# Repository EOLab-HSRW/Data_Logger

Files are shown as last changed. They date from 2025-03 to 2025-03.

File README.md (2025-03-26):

# Data Logger

## Description

This project simplifies data logging to external storage (SD card / EEPROM).

## Content

- [Hardware](#hardware)
- [Documentation](#documentation)
- [Data Types](#data-types)
- [EEPROM Data Storage Simulation](#eeprom-data-storage-simulation)
- [Data Storage Management](#data-storage-management)
- [Power Consumption Simulation](#power-consumption-simulation)
- [Power Consumption Simulation with Liquid Level Sensor](#power-consumption-simulation-with-liquid-level-sensor)
- [Modification: Addition of Liquid Sensor](#modified-data-logger--addition-of-the-liquid-level-sensor)

## Hardware

### RawWireless WisBlock

| Component  | Price (€) | Description |
|---|---|---|
| RAK11200 | 13.16 | ESP32-based module with WiFi & BLE |
| RAK11310 | 17.01 | Raspberry Pi-based module with LoRa transceiver |
| RAK19002 | 06.65 | Power slot module (Li-Ion, USB-C, Solar) |
| RAK15000 | 15.96 | EEPROM module |
| RAK15002 | 04.90 | SD card module |
| RAK12002 | 09.50 | RTC Module |
| RAK19011 | 20.90 | Development Board |
| RAK19012 | 06.90 | Development Board |
| RAK5802 | 07.97 | Interface |
| RAK1906 | 20.21 | Environmental sensor module |
| RS485 | 06.00 | Liquid level sensor + connector |
| **Total**  | **129.16** | |

## Documentation

For datasheets, quick guides, and detailed descriptions, visit:  
[docs.RawWireless.com](https://docs.RawWireless.com)

## Software

- **IDE:** Arduino IDE  
- **Project files:** Included in the project folder  

## Data Types

### 1. Timestamp  
### 2. Environmental Sensor:
   - Temperature
   - Pressure
   - Humidity
   - Gas
### 3. Liquid Level Sensor:
   - Liquid Level
   - Water Pressure

## EEPROM Data Storage Simulation

### Properties

- **Endurance:** 1 million write cycles
- **Size:** 2Mb (2,097,152 bits), organized as 262,144 words (8-bit format)
- **Power:** Standby current ~3 µA  
- **Write Mode:** 256-byte page writes (reduces wear)
- **Voltage:** 3.3V (can be controlled via the core)

### Restrictions

- **Capacity:** 2MB
- **Estimated endurance:** 2-3 months

### Storage Calculation

#### Option 1 (Without Optimization)

- 1 × 32-bit Unix timestamp
- 1 × 32-bit temperature
- 1 × 32-bit pressure
- 1 × 32-bit humidity
- 1 × 32-bit gas level
- 1 × 32-bit liquid level / water pressure
- 1 × 32-bit voltage level  
**Total:** 224 bits  

**Iterations:**  
`(2^20 * 2) / 224 = 9,362`

#### Option 2 (Optimized Storage)

- 1 × 32-bit Unix timestamp
- 1 × 16-bit temperature (-40°C to 85°C)
- 1 × 32-bit pressure
- 1 × 16-bit humidity (0% to 100%)
- 1 × 32-bit gas level
- 1 × 32-bit liquid level / water pressure (0 mm to 5000 mm)
- 1 × 16-bit voltage level (0V to 24V)  
**Total:** 144 bits  

**Iterations:**  
`(2^20 * 2) / 144 = 14,564`

**Difference:** +5,201 iterations with optimization.

### EEPROM RAK15000

- **Size:** 2Mb (2 × 2^20 = 2,097,152 bits)  
- **Storage:** Linear, sequential  
- **Address range:** 262,144 addresses (1 byte per address)

### EEPROM RAK11200 (Internal)

- **Size:** 64Kb (524,288 bits)  
- **Storage:** Linear, sequential  
- **Address range:** 16-bit (0x0000 to 0xFFFF)  
- **Note:** May contain pre-configured LoRaWAN data.

## **Metadata and Storage Layout**

EEPROM data storage is structured to ensure efficient tracking and retrieval. 
The first **8 bytes (64 bits)** are reserved for metadata:

1. **Write Counter** (20-bit) → Tracks total write cycles  
2. **Storage Position Counter** (18-bit) → Tracks the next writable address
3. **Empty Bits** (26 Bits) -> For Future Usage

**Total Metadata Size:** 64 bits

- **Write Counter:** 20 bits (supports up to 1,000,000 cycles = `0xF4240`)  
- **Storage Position Counter:** 18 bits (supports up to 262,144 addresses)  
- **Total Reserved Space:** 8 bytes

## EEPROM Data Reader / Decoder

### **Reading Process**
EEPROM contains two main sections:  
1. **Metadata:** First **8 bytes** (Indexes 0-7) store counters and tracking information.  
2. **Sensor Data Blocks:** Data is stored in **sets of 32 bytes**, following a specific sequence:
   - Temperature  
   - Pressure  
   - Humidity  
   - Gas resistance  
   - RTC timestamp

## Data Erasure Before Switching Context/Sensors

### Steps to Erase Data:

1. **Collected Data Backup:** Before erasing, ensure any necessary data is backed up.
2. **Overwrite:** With standart Value of 0x00.
3. **Metadata Reset:** is done automatically by step 2 (Overwrite).
4. **Metadata Configuration:** Setting the Address Counter to Byte 8 (0-7 Metadata).
5. **Date and Time Configuration:** Setting the Date and Time of the RTC. 

## Power Consumption Simulation

### Normal Mode

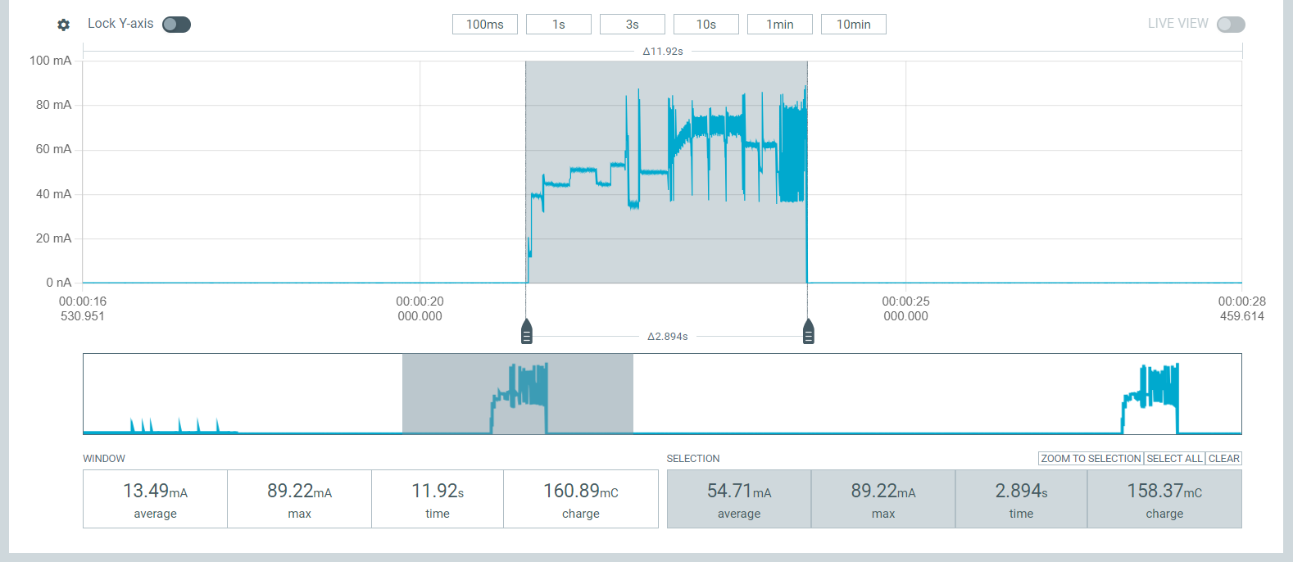
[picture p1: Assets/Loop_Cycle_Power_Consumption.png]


**Results:**

Average power consumption during deep sleep was 54.71 mA over a duration of 2.894 seconds. The battery life calculation considered the following parameters:

- Code execution duration: 3.9 seconds
- Sleep time: 1200 seconds
- Consumption during code execution: 55.03 mA
- Consumption in sleep mode: 54.71 mA
- Battery capacity: 2500 mAh with 20% discharge safety margin.

### DeepSleep Mode

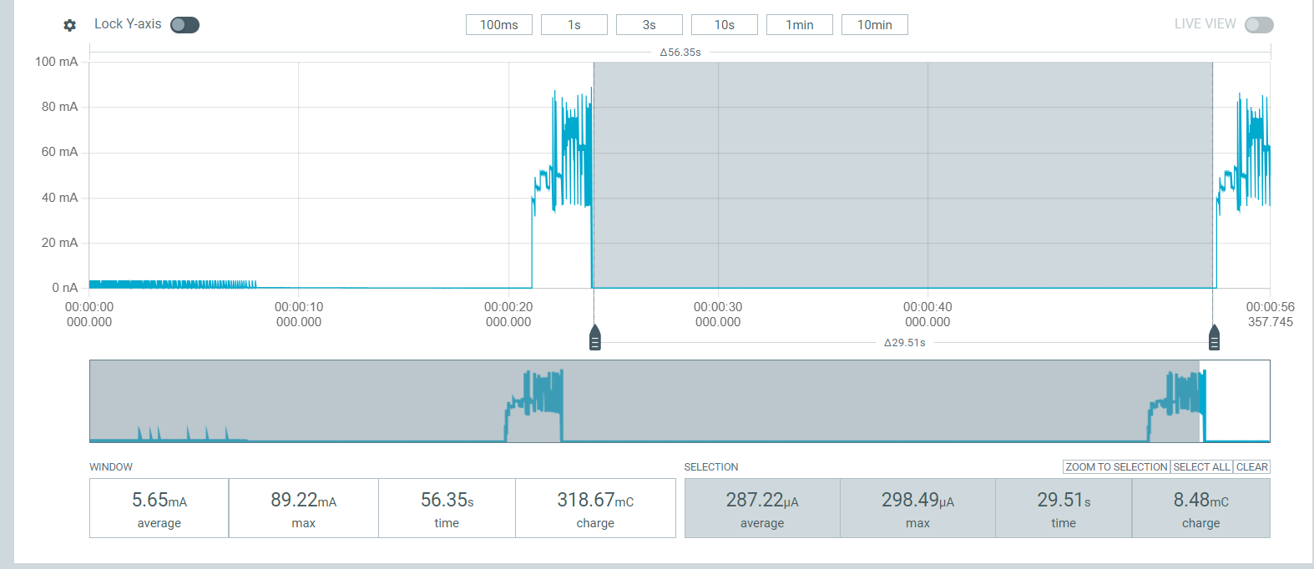
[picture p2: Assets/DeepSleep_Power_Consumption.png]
DeepSleep Mode Test Results


**Results:**

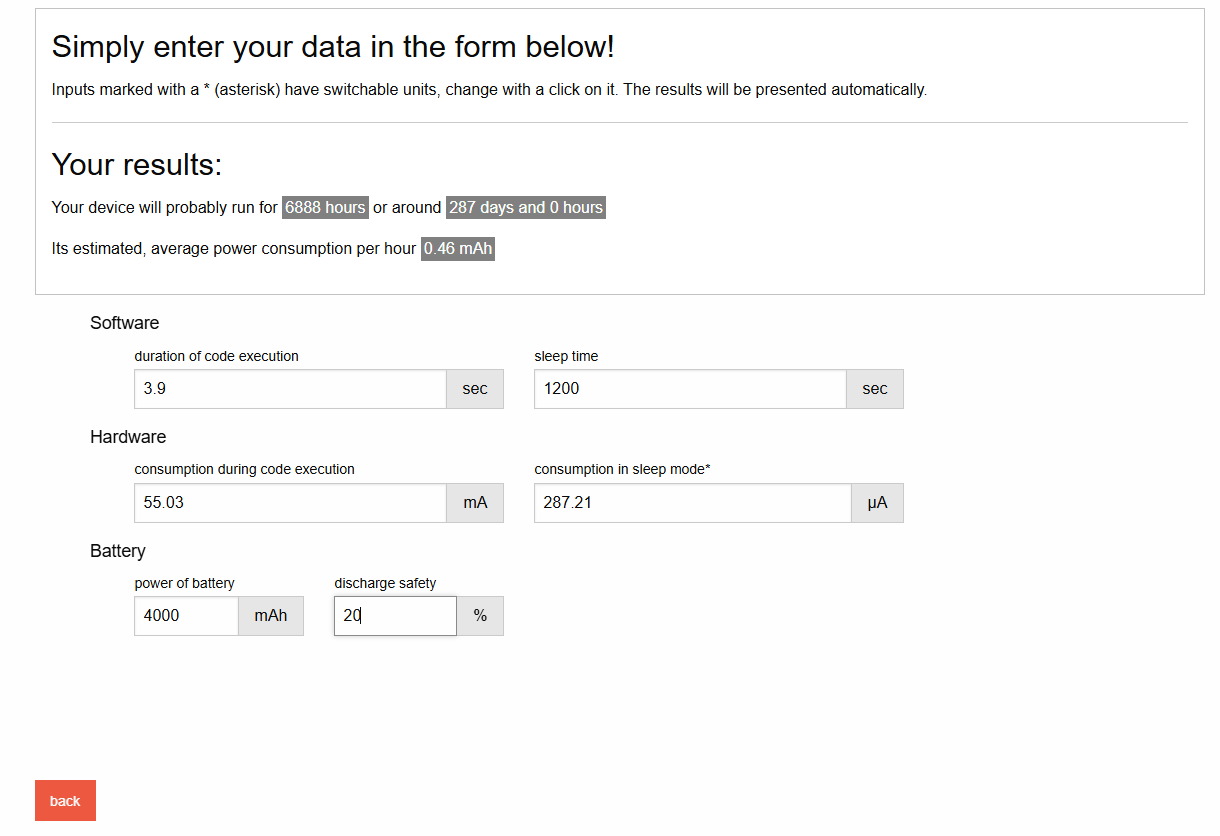
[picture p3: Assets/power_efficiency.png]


Average power consumption during deep sleep was 287.22 µA over a duration of 29.51 seconds. The battery life calculation considered the following parameters:

- Code execution duration: 3.9 seconds
- Sleep time: 1200 seconds
- Consumption during code execution: 55.03 mA
- Consumption in deep sleep mode: 287.21 µA
- Battery capacity: 2500 mAh with 20% discharge safety margin.

Estimated battery life: approximately 4305 hours, equivalent to around 179 days and 9 hours. Estimated average power consumption per hour: 0.46 mAh.

## Power Consumption Simulation with Liquid Level Sensor

### Normal Mode

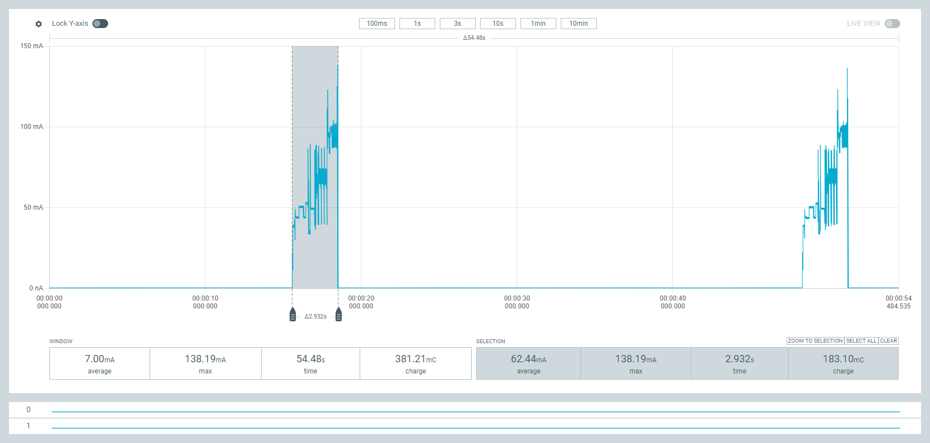
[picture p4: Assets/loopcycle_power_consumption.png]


**Results:**

Average power consumption during deep sleep was 62.44 mA over a duration of 2.932 seconds. The battery life calculation considered the following parameters:

- Code execution duration: 2.932 seconds
- Sleep time: 1200 seconds
- Consumption during code execution: 62.44 mA
- Consumption in sleep mode: 311.72 mA
- Battery capacity: 4000 mAh with 20% discharge safety margin.

### DeepSleep Mode

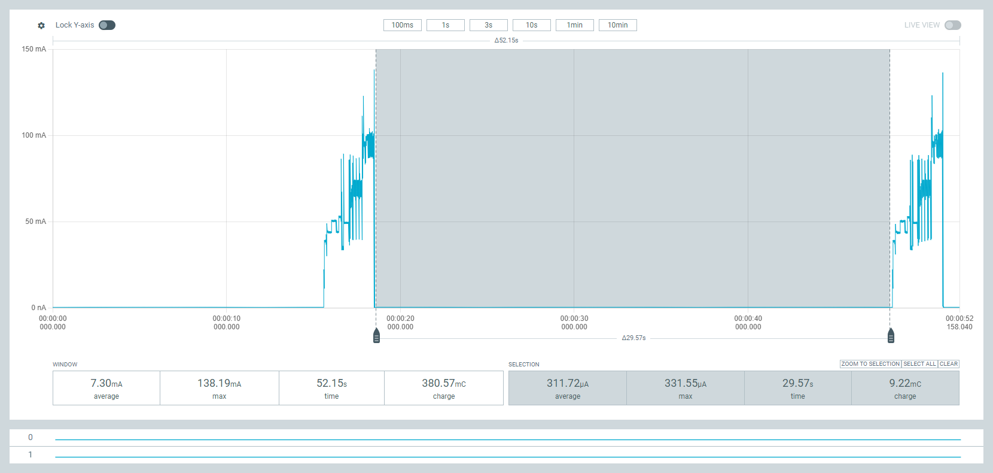
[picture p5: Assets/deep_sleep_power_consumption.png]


**Results:**

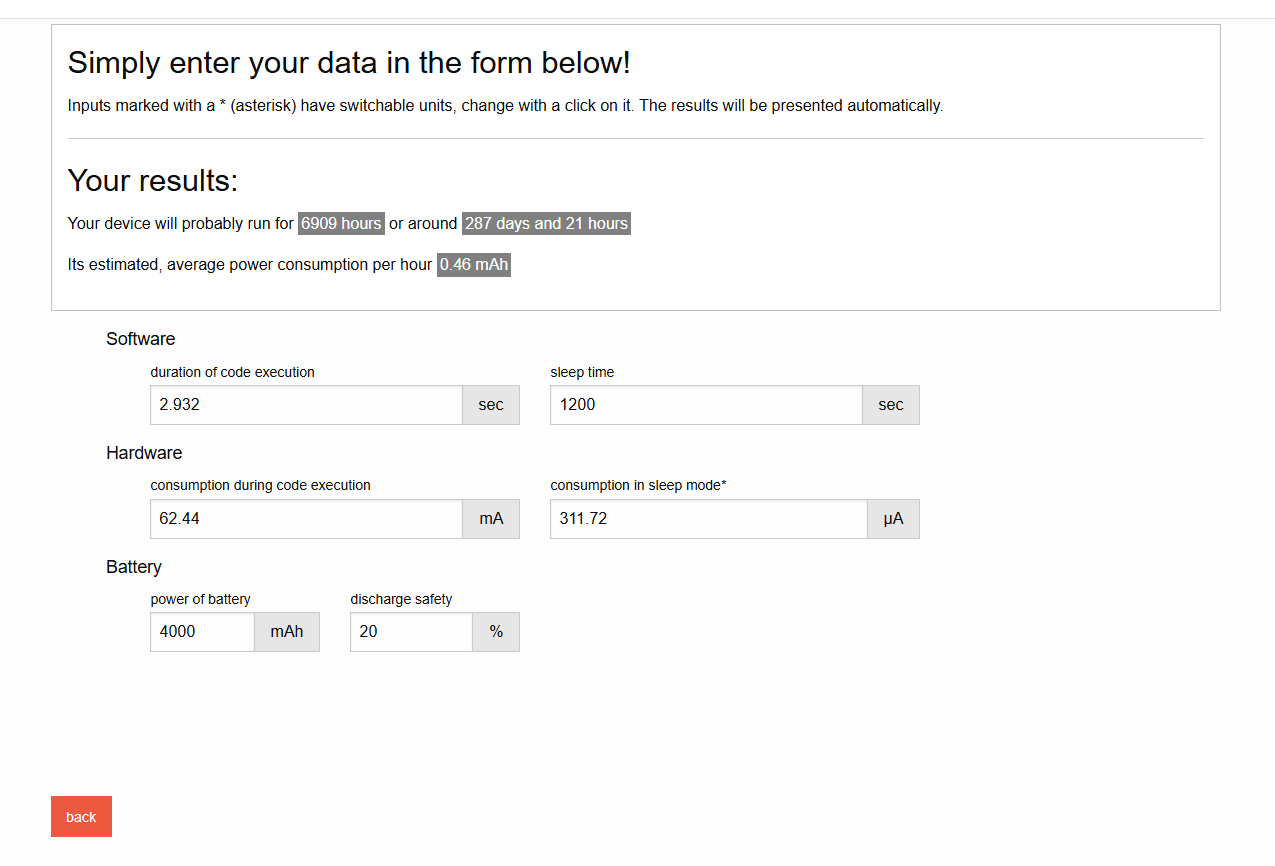
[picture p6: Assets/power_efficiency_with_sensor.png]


Average power consumption during deep sleep was 311.72 µA over a duration of 29.57 seconds. The battery life calculation considered the following parameters:

- Code execution duration: 2.932 seconds
- Sleep time: 1200 seconds
- Consumption during code execution: 62.44 mA
- Consumption in sleep mode: 311.72 mA
- Battery capacity: 4000 mAh with 20% discharge safety margin.

Estimated battery life: approximately 6909 hours, equivalent to around 287 days and 21 hours. Estimated average power consumption per hour: 0.46 mAh.

## Modified Data Logger / Addition of the Liquid Level Sensor

### RS485 Liquid Level Sensor

#### Overview
The **RS485 Liquid Level Sensor** is a high-precision sensor designed for measuring liquid levels. 

#### Features
**Anti-corrosion material** – Durable and resistant  
**Modbus-RTU communication** – Compatible with PLCs, displays, and data loggers  
**High-precision sensor** – ±0.25% accuracy  
**Wide operating voltage** – 11–30V DC  
**Fast response time** – ≤ 5 ms  

### Technical Specifications

| Parameter | Value |
|---|---|
| **Measurement Range** | 0 ~ 5 meters |
| **Output** | RS485 (Modbus-RTU) |
| **Accuracy** | ±0.25% F.S. |
| **Temperature Range** | -40°C to +85°C |
| **Material** | 304/316L Stainless Steel |
| **Power Supply** | 11–30V DC |
| **Weight** | 670 g |

#### Wiring
The sensor is connected via an **Aviation Connector** interface. The pin configuration is:

| Pin | Description |
|-----|---|
| 12V (RAK5801) | 12V Power Supply (VCC Sensor)  |
| A1  (RAK5801) | GND (GND Sensor) |

#### Modbus-RTU Communication
#### Default Communication Settings:
- **Baud Rate**: 9600 bps (supports 1200–115200 bps)
  **Note:** Changes to baud rate and slave address take effect immediately. If not, restart the sensor.

### RAK5801 Sensor Module

#### Overview
The **RAK5801** is a high-performance sensor module designed for industrial and environmental monitoring applications. 
Part of the WisBlock ecosystem, it offers robust data acquisition and is engineered for reliable performance even in harsh conditions.

#### Features
- **High-Precision Measurement** – accurate data collection.
- **Rugged Design** –  reliably in industrial environments.
- **Seamless Integration** – Easily integrates.
- **Versatile Interfaces** – Supports standard communication protocols.

### RAK19002 Sensor Module

#### Overview
The **RAK19002** is a sensor module developed for versatile IoT applications within the WisBlock ecosystem.
It is designed to provide reliable, accurate measurements for various environmental and application-specific parameters.

#### Features
- **Compact & Low Power** – Optimized for energy-efficiency.
- **High Accuracy** – Ensures precise measurement data.
- **Plug-and-Play Integration** – interfaces with WisBlock.
- **Robust Performance** – Suitable for operating conditions.

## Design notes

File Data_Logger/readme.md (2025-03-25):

# **Software Documentation: Arduino Data Logger**

## Content

- [Overview](#1-overview)
- [File Structure](#2-file-structure)
- [System Workflow](#3-system-workflow)
- [Function Summary](#4-functions-summary)
- [Data Isolation / Storage](#5-isolation-of-counter-and-storage-data)
- [Future Enhancements](#6-future-enhancements)

## **1. Overview**
This project implements a data logging system using an Arduino-compatible microcontroller. The system reads environmental sensor data, stores it in EEPROM, and writes it to an SD card. Additionally, it integrates a Real-Time Clock (RTC) for timestamping logged values.

## **2. File Structure**
The project consists of several modules:

### **2.1 datalogger.ino**
- **Purpose:** Main entry point of the application.
- **Functionality:**
  - Initializes required components (SD card, EEPROM, BME680 sensor, and RTC).
  - Collects environmental sensor data.
  - Manages data storage in EEPROM and SD card.
  - Ensures proper communication and handling of time-sensitive operations.

### **2.2 bme680_sensor.h / bme680_sensor.cpp**
- **Purpose:** Interface for the BME680 environmental sensor.
- **Functionality:**
  - Initializes the BME680 sensor and configures its settings.
  - Reads temperature, pressure, humidity, and gas resistance values.
  - Ensures data consistency by converting floating values to integers (x100 scaling).
  - Provides both static and dynamic memory allocation options for sensor data retrieval.

### **2.3 eeprom.h / eeprom.cpp**
- **Purpose:** EEPROM memory management.
- **Functionality:**
  - Initializes EEPROM communication over I2C.
  - Provides functions for reading and writing data to EEPROM.
  - Implements memory addressing logic to ensure sequential data storage.
  - Includes power control for EEPROM.

### **2.4 sdcard.h / sdcard.cpp**
- **Purpose:** SD card file management.
- **Functionality:**
  - Provides functions to read, write, and delete files on an SD card.
  - Uses SPI communication for SD card access.
  - Supports CSV-style data logging with automatic separation.
  - Implements error handling for file operations.
### **2.5 rtc.h / rtc.cpp**
- **Purpose:** Real-Time Clock (RTC) management.
- **Functionality:**
  - Provides functions to retrieve the current time in a specified format.
  - Uses I2C communication for interaction with the RTC module.
  - Supports setting and updating the date and time.
  - Includes functions for reading from and writing to the internal EEPROM.
  - Implements error handling for RTC operations.

## **3. System Workflow**
1. **Initialization:**
   - The system starts by initializing serial communication, EEPROM, SD card, RTC, and the BME680 sensor.
   - It checks the presence and accessibility of each module.

2. **Data Collection:**
   - The main loop collects sensor readings every 5 minutes using `get_Environment()`.
   - The retrieved data is formatted and prepared for storage.

3. **Data Storage:**
   - Data is split into 8-bit chunks and stored in EEPROM sequentially.
   - The same data is written to the SD card for long-term storage.

4. **Error Handling:**
   - The system checks for sensor availability and EEPROM communication before reading or writing data.
   - Serial messages indicate any failures, such as missing EEPROM or SD card issues.

## **4. Functions Summary**
| Function Name | File | Description |
|---|---|---|
| `void get_Values()` | datalogger.ino | Retrieves sensor data and prints it via serial. |
| `bool bme680_init()` | bme680_sensor.cpp | Initializes the BME680 sensor. |
| `void get_Environment(long values[])` | bme680_sensor.cpp | Reads sensor values and converts them to integers. |
| `bool eeprom_init()` | eeprom.cpp | Initializes and verifies EEPROM availability. |
| `void readData(long address)` | eeprom.cpp | Reads data from EEPROM. |
| `void writeData(long* data, size_t size)` | eeprom.cpp | Writes data to EEPROM and increments the address counter. |
| `long getCounter()` | eeprom.cpp | Returns the extracted Total Counter. |
| `void setCounter(long counter)` | eeprom.cpp | Sets the Total Counter. |
| `void getAddress()` | eeprom.cpp | Returns the extracted Address Counter. |
| `void setAddress(long address)` | eeprom.cpp | Sets the Address Counter. |
| `void readFile(const char *path)` | sdcard.cpp | Reads a file from the SD card and prints its content. |
| `void writeFile(const char *path, const char *message)` | sdcard.cpp | Appends data to an SD card file with CSV formatting. |
| `void deleteFile(const char *path)` | sdcard.cpp | Deletes a specified file from the SD card. |
| `String combineToString(long *data, size_t size)` | sdcard.cpp | Combines the collected data into one String. |
| `void rtc_init()` | rtc.cpp | Initializes and verifies RTC availability. |
| `unsigned long rtcGetTimeLong()` | rtc.cpp |  Returns the current time. |

## **5. Isolation of Counter and Storage Data**

### **64 Bit Meta Data**

```
0000 0000 0000 0000 0000 0000 0000 0000 0000 0000 0000 0000  0000 0000 0000 0000
------------------------                                                         Total (20)
                         ----------------------                                  Address (18)
                                               --------------------------------- Free (26)
```

---

### **Total Counter Isolation**
| Step | Description |
|---|---|
| **1** | Read **Byte 1-3** (Indexes 0-2) |
| **2** | Perform a Bit Shift by 4 to the right on the third byte |
| **3** | Perform a Bit Shift by 4 to the left to restore the original value |
| **4** | Convert to `long` to obtain the exact value from the bytes |
| **5** | Shift the first byte 16 bits to the left |
| **6** | Shift the second byte 8 bits to the left |
| **7** | Sum all values to get the final total |

### **Total Counter Reset**
| Step | Description |
|---|---|
| **1** | Generate 3 masks to extract the 20 bits from the long parameter |
| **2** | Masks: `0xff0000`, `0x00ff00`, and `0x0000ff` |
| **3** | Set byte 1 and byte 2 with the extracted values |
| **4** | Read byte 3 again, perform a bit shift by 4 to the left and right to align with subsequent metadata |
| **5** | Perform an OR operation with the adjusted `val3` and set the third byte |

---

### **Address Counter Isolation**
| Step | Description |
|---|---|
| **1** | Read **Byte 3-5** (Indexes 2-4) |
| **2** | Perform a Bit Shift by 4 to the right on the second byte |
| **3** | Perform a Bit Shift by 4 to the left to restore the original value |
| **4** | Convert to `long` to obtain the exact value from the bytes |
| **5** | Shift the first byte 16 bits to the left |
| **6** | Shift the third byte 8 bits to the left |
| **7** | Sum all values to get the final address |

### **Address Counter Reset**
| Step | Description |
|---|---|
| **1** | Generate 3 masks to extract the 20 bits from the long parameter |
| **2** | Masks: `0xff0000`, `0x00ff00`, and `0x0000ff` |
| **3** | Set byte 2 with the extracted value |
| **4** | Read byte 1 and byte 3 again, perform a bit shift by 6 to the left and right for byte 3, and by 4 to the left and right for byte 1 to align with subsequent metadata |
| **5** | Perform an OR operation with `val1` and `val3` from behind and set the first and third bytes |

---

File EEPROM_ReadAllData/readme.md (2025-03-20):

# EEPROM Reader

This project demonstrates how to read data from an I2C EEPROM and write it to an SD card. The system is built with an ESP32, EEPROM module, and an SD card module. It features initialization functions for the EEPROM and SD card, as well as data retrieval functions to read from the EEPROM and write the data to a file on the SD card.

## Features

### `sdcard_init()`
Initializes the SD card module and checks for a successful connection. This function ensures that the SD card is properly mounted and ready for writing.

### `writeFile(path, message)`
Writes a message to a file on the SD card. If the file doesn't exist, it is created. This function is used to store the data read from the EEPROM to the SD card.

### `eeprom_init()`
Initializes the EEPROM module and verifies the connection over I2C. It ensures that the EEPROM is properly connected to the ESP32 and ready for data reading.

### `readData(address, buffer, size)`
Reads data from the EEPROM at a specified address and stores it in the provided buffer. This function is used to retrieve both metadata and sensor data from the EEPROM.

### `getMetaData()`
This function reads the first 8 bytes of the EEPROM (the metadata) and processes the information. It calculates the total counter, address, and available free space based on the EEPROM contents.

### `getSensorData(counterAddress, i)`
This function reads sensor data from the EEPROM at a specific address and converts the data into a float value. The values are divided by 100 to convert them into a human-readable format (unless the value represents a timestamp). This function is used to process sensor readings for logging.

## Hardware Requirements

- ESP32 RAK11200
- EEPROM RAK15000
- SD-Module RAK15002

## Used Libraries

- [Adafruit EEPROM I2C](https://github.com/adafruit/Adafruit_EEPROM_I2C)
- [SD](https://www.arduino.cc/en/Reference/SD)

## Code Walkthrough

### Setup Process

1. **Serial Initialization:**
   The code starts by initializing the Serial communication at a baud rate of 115200. This allows you to monitor the progress of the program in the Serial Monitor.

2. **Initializing EEPROM and SD Card:**
   The functions `eeprom_init()` and `sdcard_init()` are called to initialize both the EEPROM and the SD card. These functions ensure that both components are correctly connected and operational.

3. **Reading Meta Data:**
   The `getMetaData()` function is called to read the first 8 bytes of data from the EEPROM. This metadata provides useful information about the EEPROM's state, such as the total counter, address, and available space. This data is then written to a file on the SD card as `Eeprom.csv`.

4. **Reading Sensor Data:**
   The program then reads sensor data from the EEPROM. A loop is used to read the data in chunks (50 sensor readings in this example). It reads 4 bytes at a time (each value is 4 bytes), and the data is processed by the `getSensorData()` function, which converts the raw bytes into float values. These values are then written to the SD card.

5. **Writing to SD Card:**
   The `writeFile()` function is used to write the meta data and sensor data to the SD card. The sensor data is written in CSV format, where each sensor reading is followed by a comma, and new lines are added after every 8 sensor readings.

### Main Functions

#### `getMetaData()`
The `getMetaData()` function reads 8 bytes from the EEPROM (the metadata section). It extracts and calculates important values such as:

- **Total Counter:** The total number of data points in the EEPROM.
- **Address:** The starting address for the sensor data.
- **Free Space:** The available space left in the EEPROM.

This metadata is formatted into a CSV string and returned.

#### `getSensorData(counterAddress, i)`
This function reads sensor data from the EEPROM at the specified address. It extracts 4 bytes of data and combines them into a single long value. This value is then divided by 100 to convert it into a floating-point value (except for timestamps, which are left as raw values). The processed data is returned as a string, and if it is the last value in a set, a newline character is added.

### Code Structure

The code is organized into different files:

- **`calculator.h`**: Contains declarations for the `getMetaData()` and `getSensorData()` functions.
- **`eeprom.h`**: Contains the functions related to reading data from the EEPROM.
- **`sdcard.h`**: Contains the functions related to initializing and writing data to the SD card.

Each of these files is included in the main Arduino file for initialization and processing of data.

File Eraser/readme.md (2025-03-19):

# Eraser

This project provides a simple library for working with I2C EEPROMs using Arduino. 
The library includes functions to initialize the EEPROM, reset data, and configure the address.

## Features

### `eeprom_init()`
Initializes the EEPROM connection via I2C and checks if the EEPROM is present.

### `readData(address, buffer, size)`
Reads data from the EEPROM at a specified address and stores it in the provided buffer.

### `reset(size)`
Overwrites the first `size` bytes of the EEPROM with the value `0xFF`.

### `configAddress()`
Sets the default value for the EEPROM address counter to manage the memory correctly.

## Hardware Requirements

- ESP32  RAK11200
- EEPROM RAK15000

## Used Libraries

- [Adafruit EEPROM I2C](https://github.com/adafruit/Adafruit_EEPROM_I2C)

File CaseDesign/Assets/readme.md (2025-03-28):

# Case Design and Model

## Box4u Case Details

### Base

The base of the case has the following specifications:
- Rounded corners (R6)
- Outer dimensions approximately 122/121.3 mm (width) and 120/119.3 mm (height)
- Main rectangle dimensions: width 116/115.3 mm (with a tolerance of +/- 0.35 mm), height 114/113.3 mm
- Inner dimensions (main section): width 97.2/96.5 mm, height 77.2/76.5 mm, depth 4/6.5 mm
- Cutouts: ø3 mm and ø8.5 mm

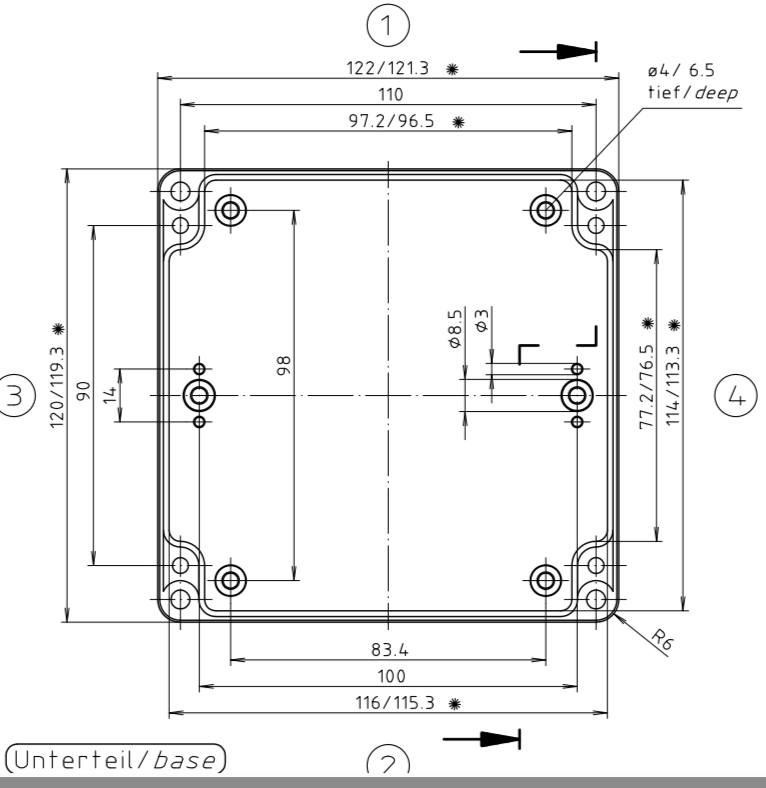
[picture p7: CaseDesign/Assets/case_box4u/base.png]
Base Sketch


### Lid

The lid of the case has the following specifications:
- Rounded corners (R6)
- Outer dimensions 122/121.5 mm (width) and 120/119.5 mm (height)
- Main rectangle dimensions: width 113/112.6 mm (with a tolerance of +/- 0.35 mm), height 111/110.6 mm
- Inner dimensions (main section): width 94.2/93.8 mm, height 74.2/73.8 mm

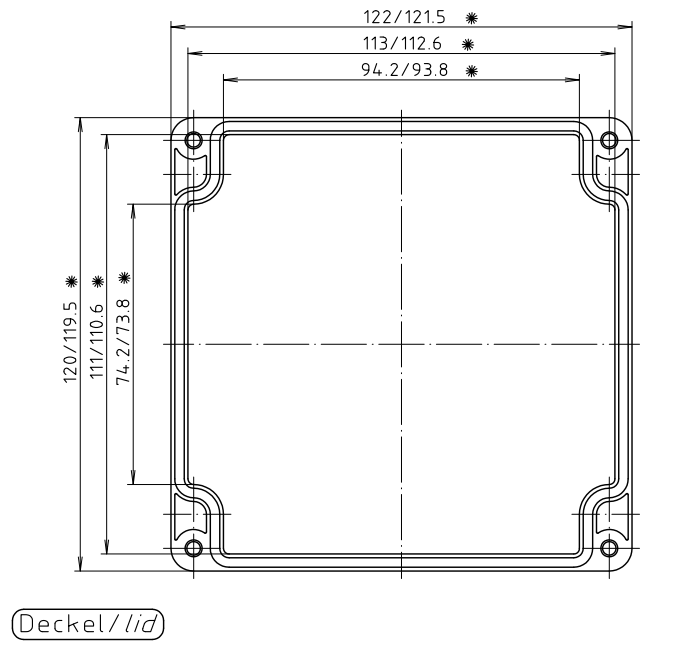
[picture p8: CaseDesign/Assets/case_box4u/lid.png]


### Depth

The side view reveals the following specifications:

Lid:
- 15 mm depth including 3 mm thickness on top of the lid
- Total height of 55 mm
- Height without bottom and top plate thickness: 48 mm
- 40 mm including 4 mm bottom plate for the base case

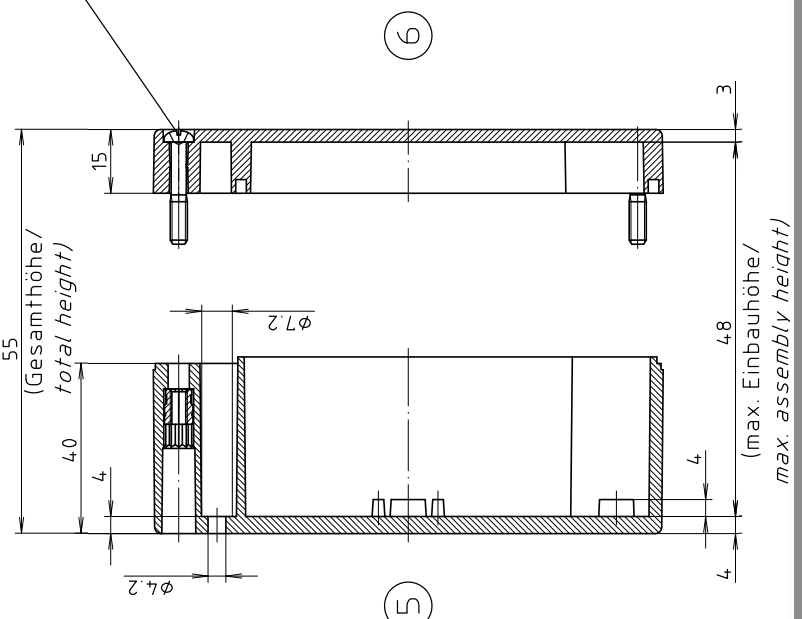
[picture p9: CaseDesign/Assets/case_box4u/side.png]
Side View


### Screw Detail

Cylinder Screws (M4 x 24 / 10 (DIN EN ISO 7045/))

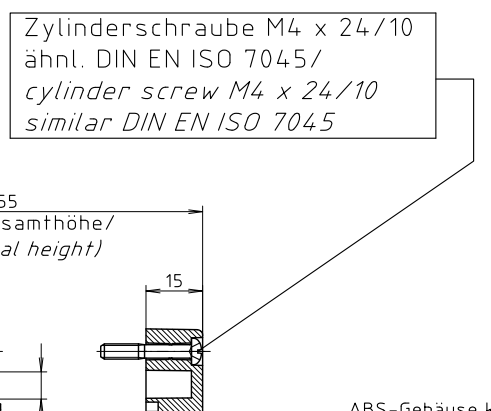
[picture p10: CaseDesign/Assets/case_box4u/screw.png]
Detail of Screw


## RAK Base Board Details

The board has the following specifications:
- a main rectangle of 69 (width) to 67 (height)
- 3 rectangular cutouts with 2x of 8mm * 14.50 and 1x 13 mm * 8mm
- 4x screw holes (inner radius of ø2.5 mm) / (outer radius ø5 mm)

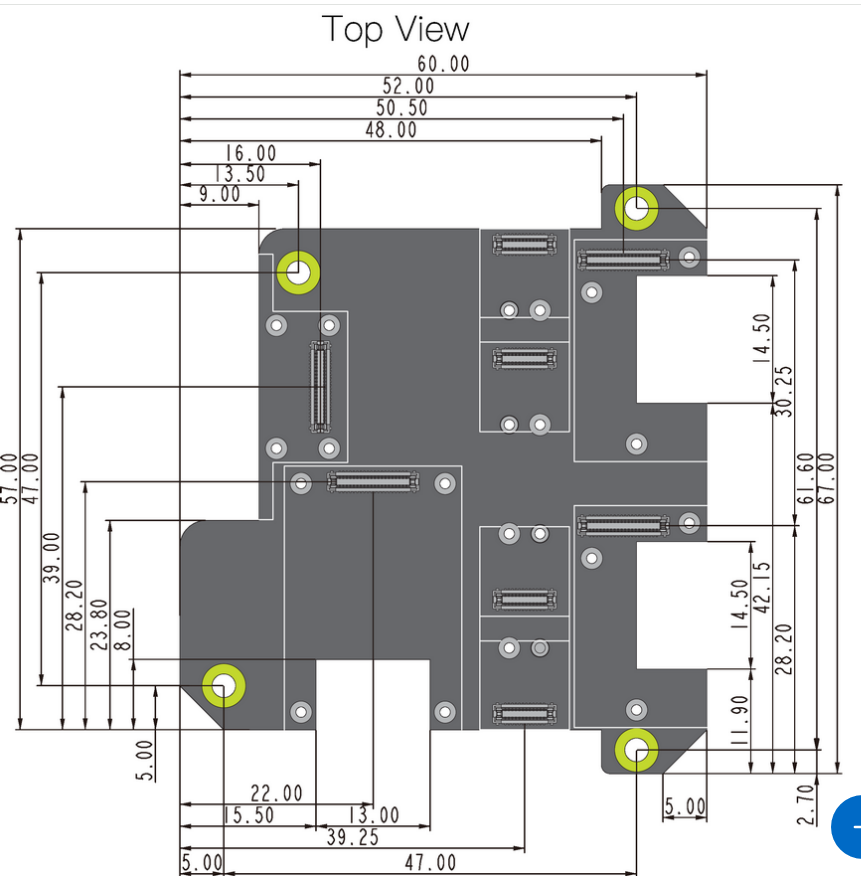
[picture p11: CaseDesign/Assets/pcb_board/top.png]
Board Sketch Top

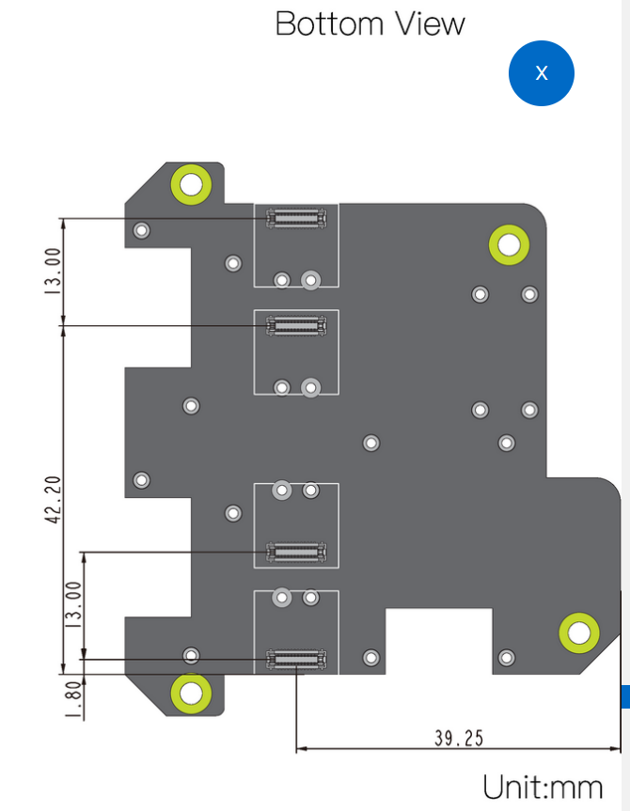
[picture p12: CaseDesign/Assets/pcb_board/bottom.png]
Board Sketch Bottom


## 3D Modelling in Auto Fusion 360

### Step 1: Basement

We start with the sketch of the basement.
Configure the sizes as mentioned earlier above.
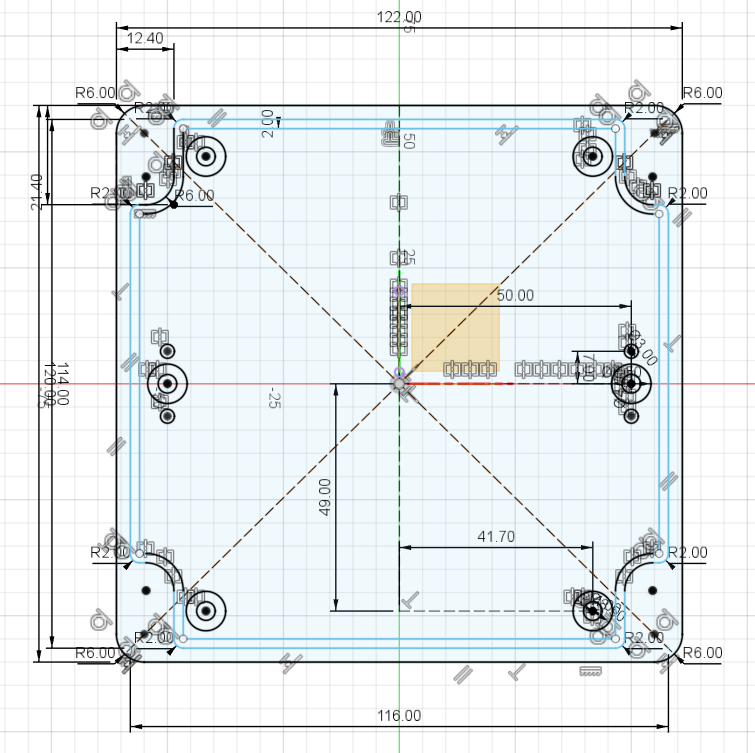
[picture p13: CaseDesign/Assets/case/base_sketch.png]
Base Sketch

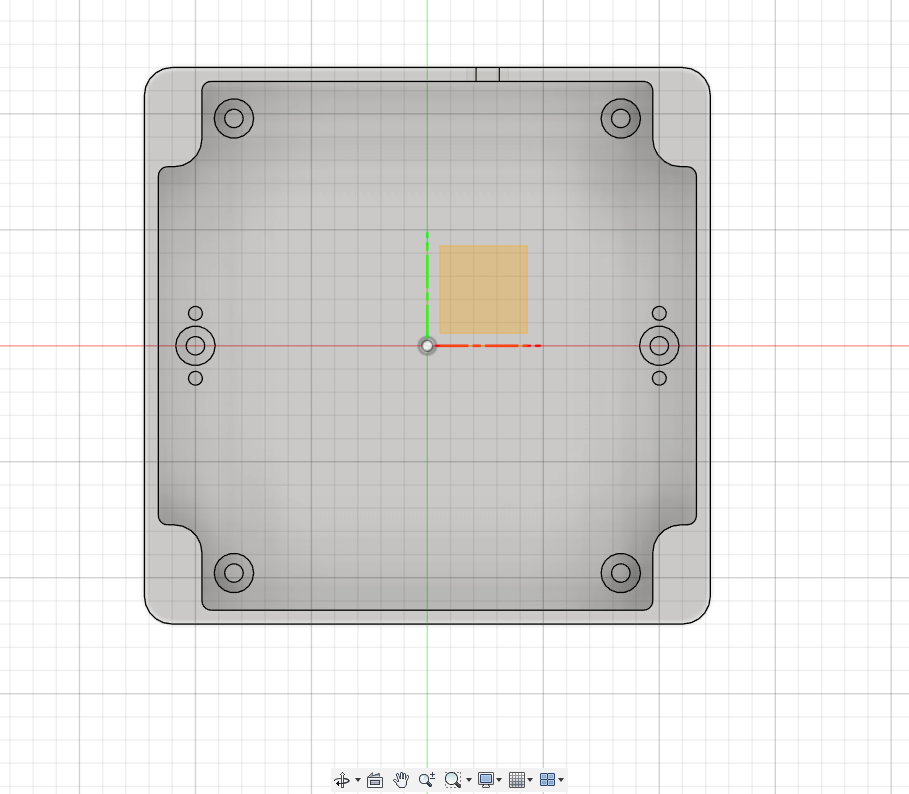
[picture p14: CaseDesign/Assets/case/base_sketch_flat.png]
Base Sketch Flat


Then we extrude the needed areas for the sides and also the outer circles for the screws.
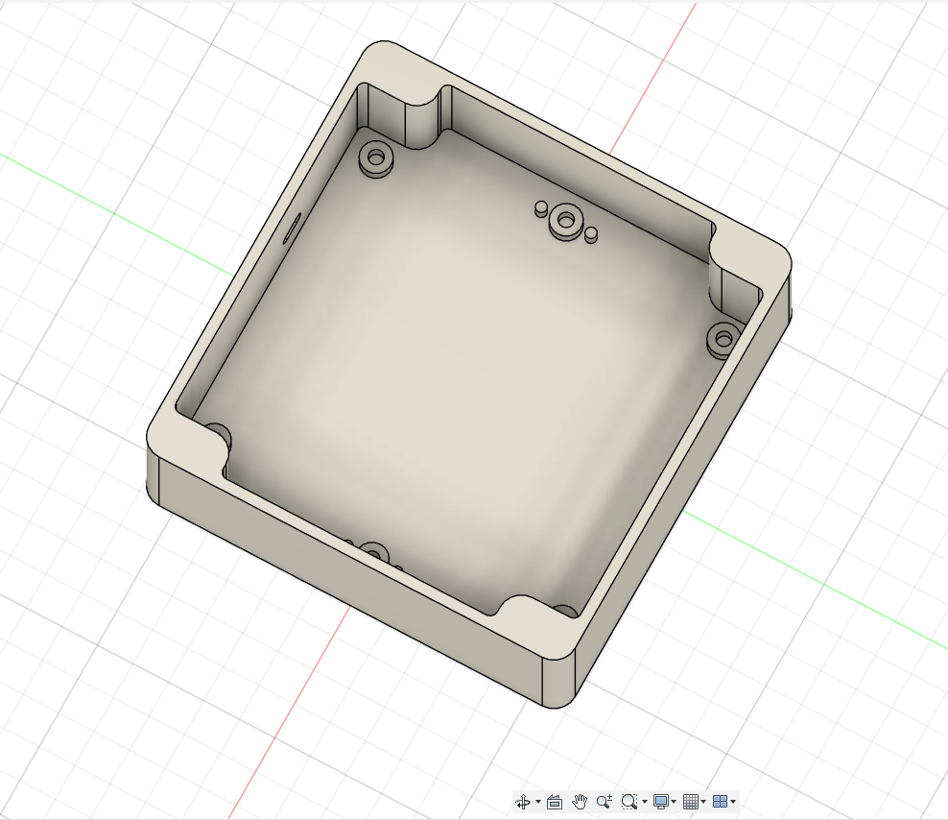
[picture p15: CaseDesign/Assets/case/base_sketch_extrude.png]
Base Sketch Extrude


### Step 2: Lid

Next, configure the sizes for the lid as in step 1.

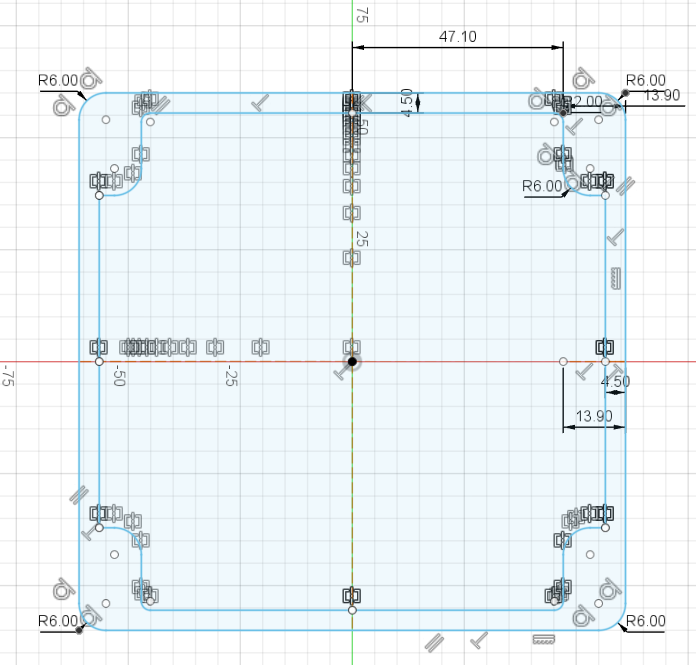
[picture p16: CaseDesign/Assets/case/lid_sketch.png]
Lid Sketch

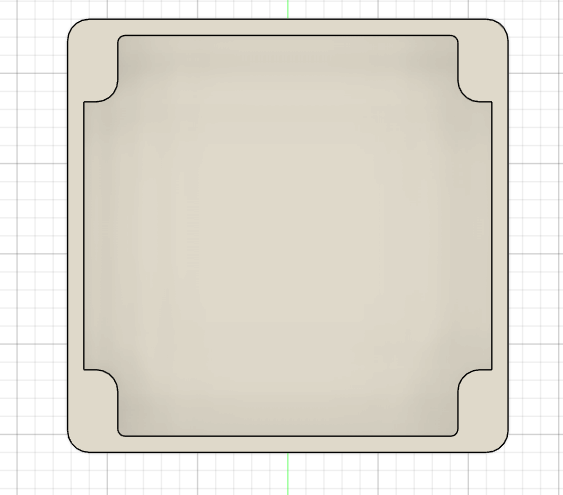
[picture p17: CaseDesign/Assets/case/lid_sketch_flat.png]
Lid Sketch Flat


Extrude the specified areas.

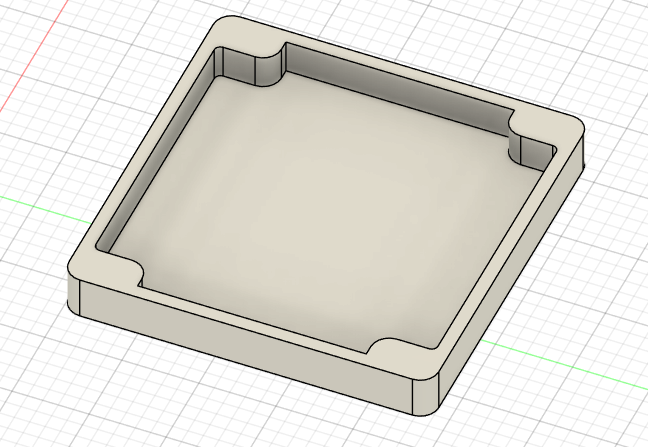
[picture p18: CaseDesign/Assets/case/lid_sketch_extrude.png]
Lid Sketch Extrude


### Step 3: Board

Continue with the RAK board sketch and set the sizes as shown.
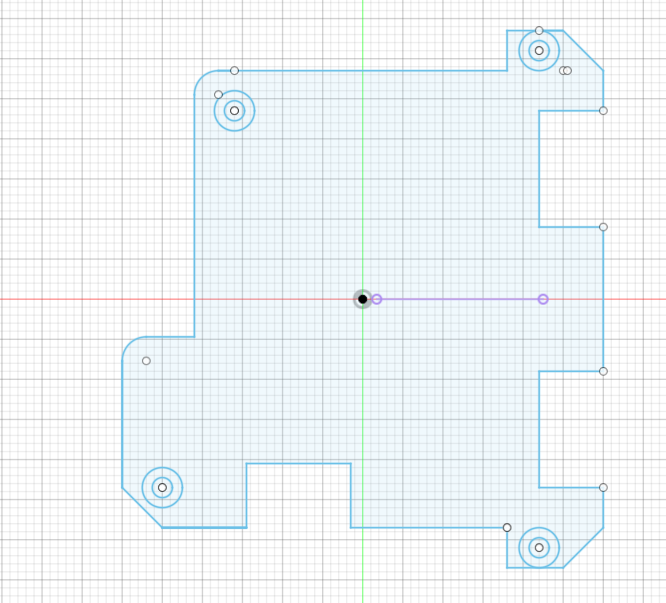
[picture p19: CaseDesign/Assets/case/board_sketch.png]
Board Sketch

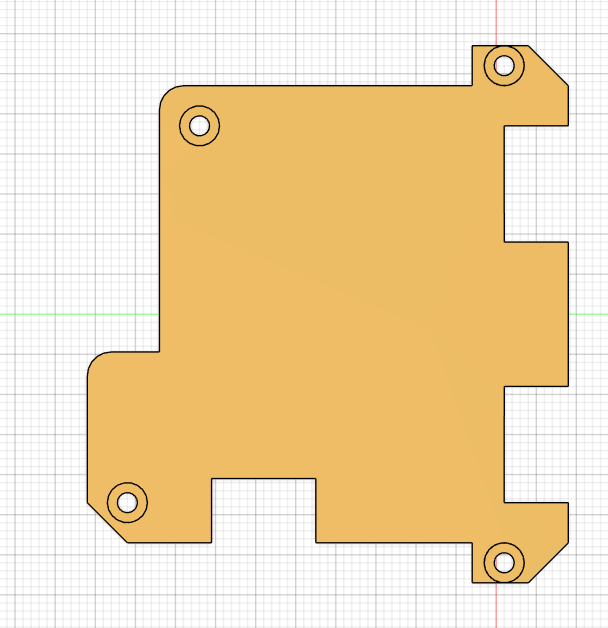
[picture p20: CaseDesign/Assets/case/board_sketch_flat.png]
Board Sketch Flat


Extrude the needed areas.
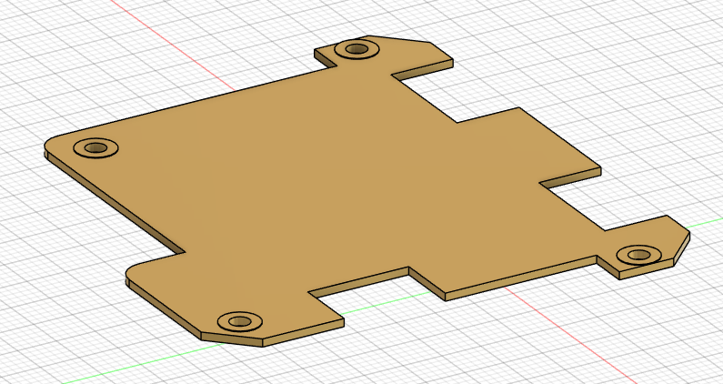
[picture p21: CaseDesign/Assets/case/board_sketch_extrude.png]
Board Sketch Extrude


### Step 4: Outline Basement

Set the sizes for the basement outline to fasten the board on the case.
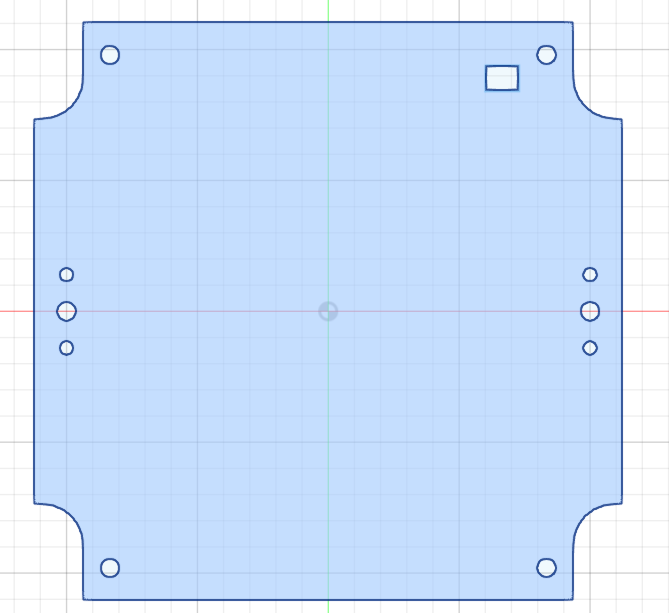
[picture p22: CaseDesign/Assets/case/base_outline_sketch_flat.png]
Base Outline Sketch Flat


Finish with an extrude of the needed areas.
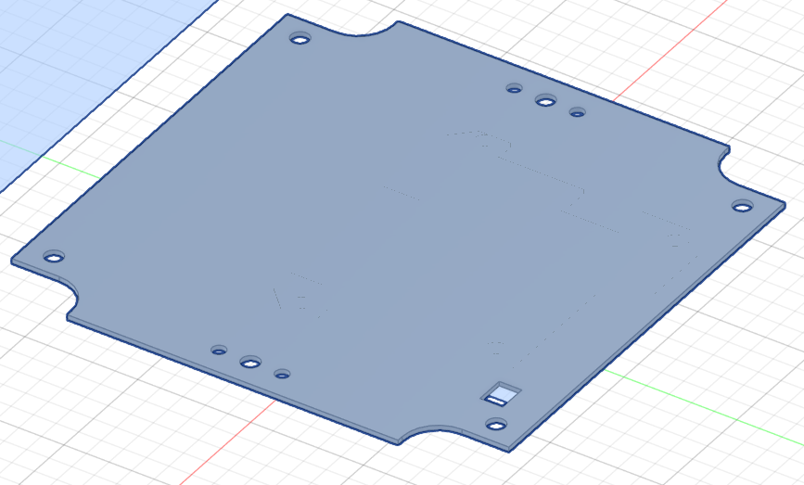
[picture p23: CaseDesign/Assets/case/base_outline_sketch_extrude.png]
Base Outline Sketch Extrude


### Step 5: Results

The results should be as follows:
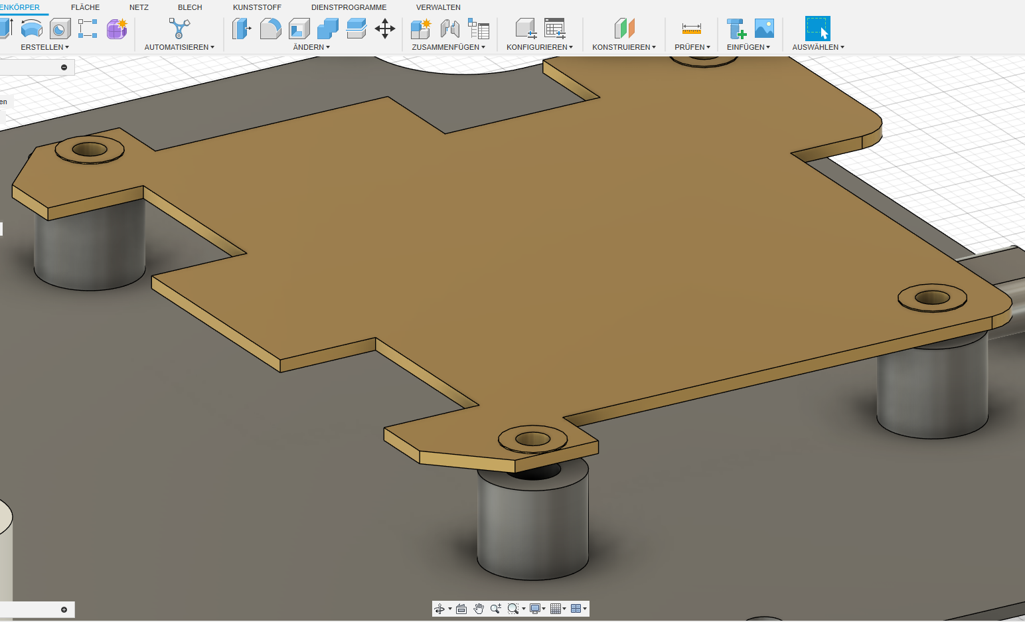
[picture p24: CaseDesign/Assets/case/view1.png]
View

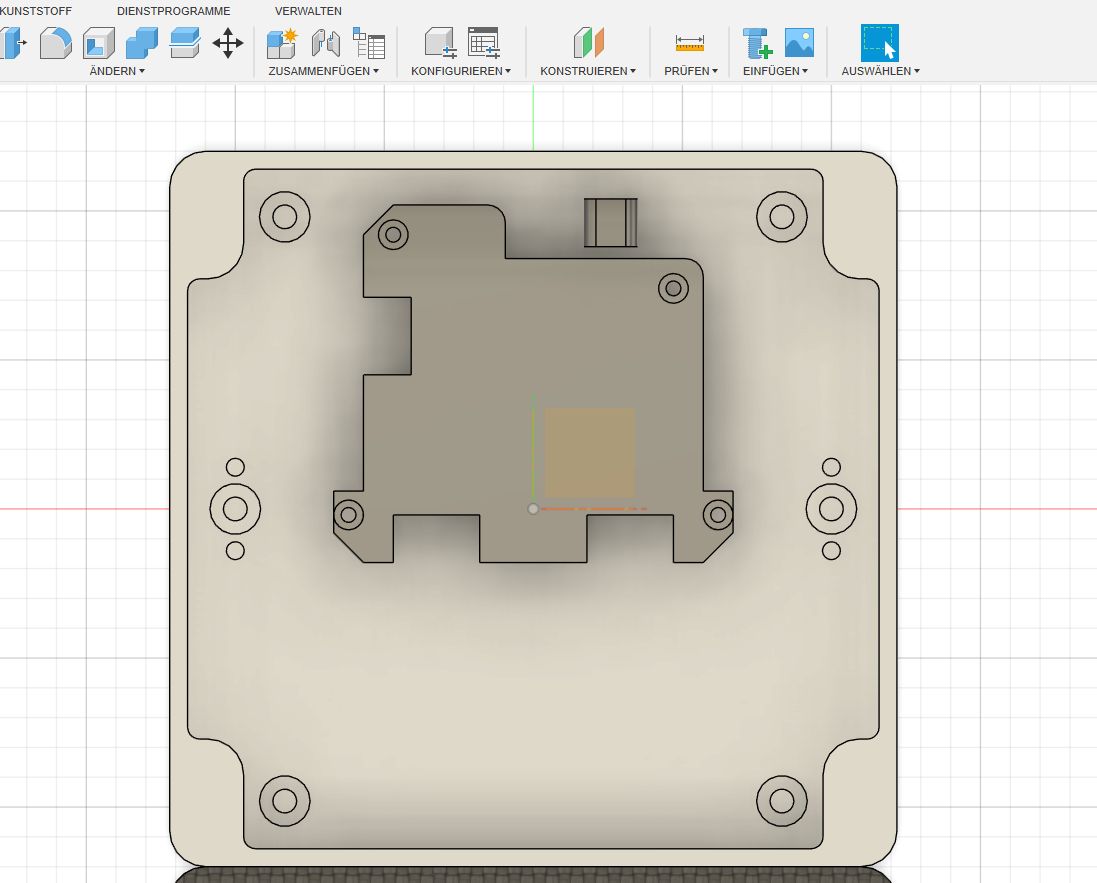
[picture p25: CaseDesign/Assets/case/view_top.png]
Top View

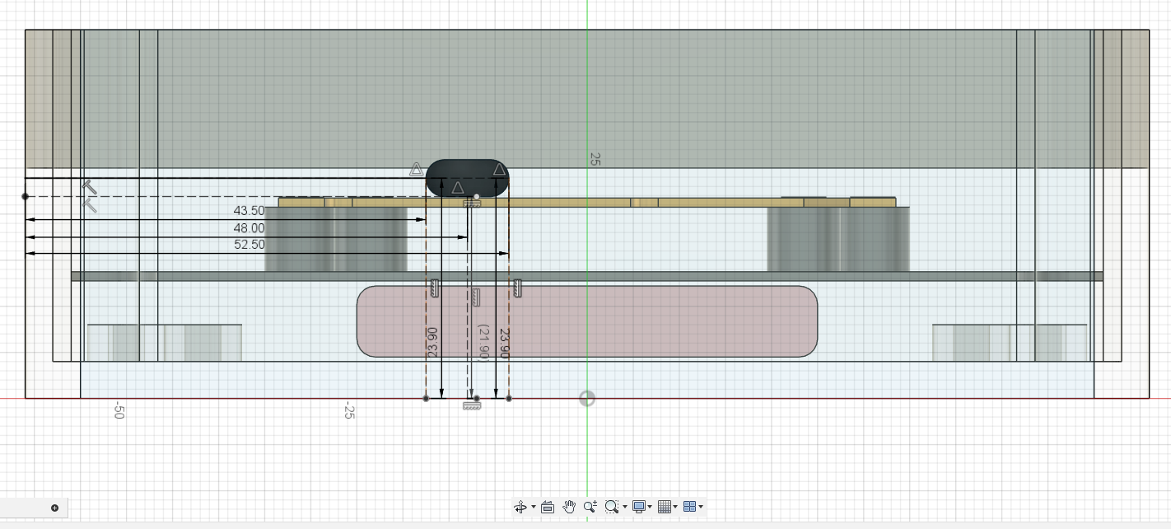
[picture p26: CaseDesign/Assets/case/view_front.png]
Front View

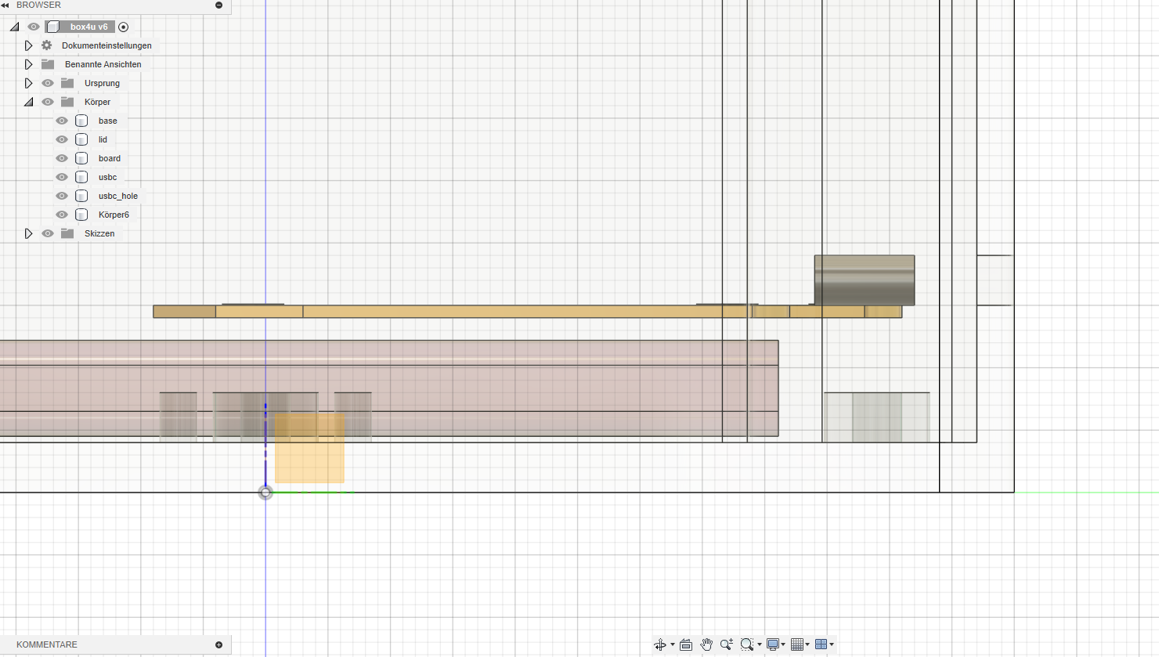
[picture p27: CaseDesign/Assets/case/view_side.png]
Side View

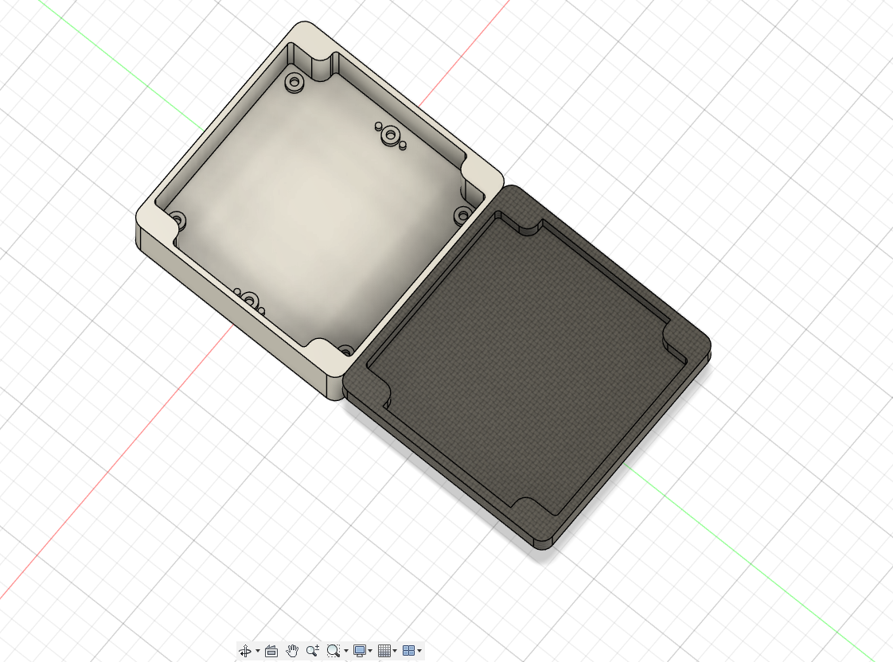
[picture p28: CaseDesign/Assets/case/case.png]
Endresult


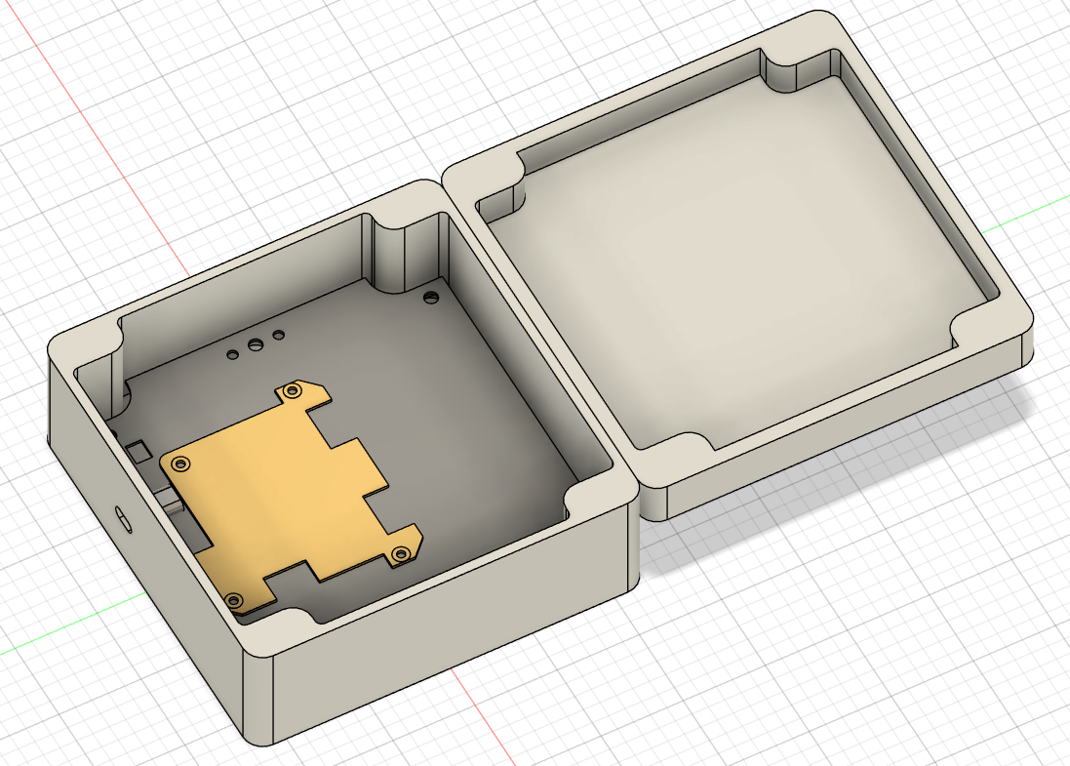
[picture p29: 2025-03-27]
CaseDesign/Assets/case/base_ske.png

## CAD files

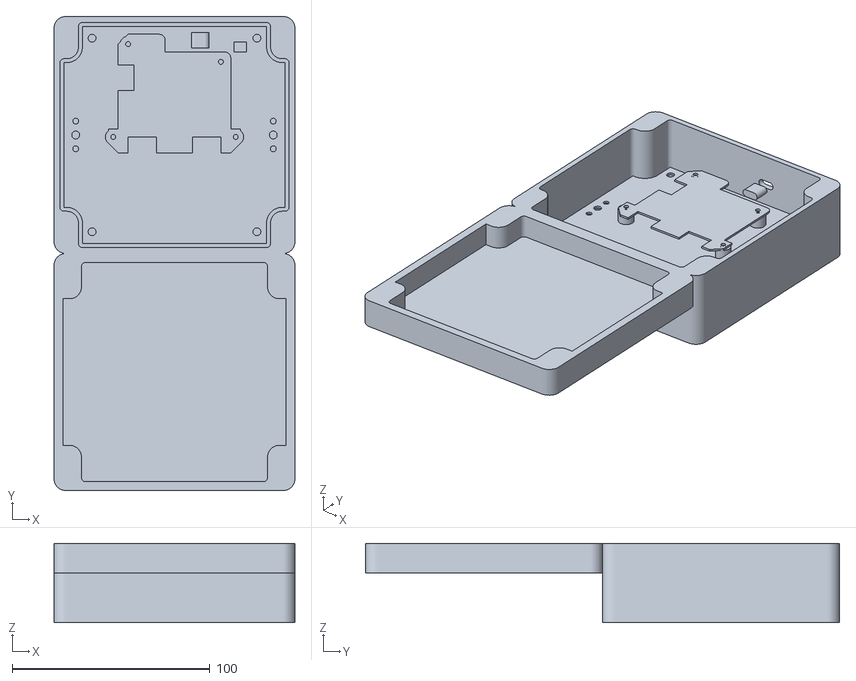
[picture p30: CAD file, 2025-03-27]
CaseDesign/box4u.stl
122.0 x 240.0 x 40.0

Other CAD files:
CaseDesign/box4u.f3d

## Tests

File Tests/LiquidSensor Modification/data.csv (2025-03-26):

24.57 | 102252.00 | 36.08 | 15996.00 | 4016.01 | 2025-3-24T15:18:4Z
24.67 | 102249.00 | 35.03 | 22998.00 | 4029.35 | 2025-3-24T15:18:37Z
24.69 | 102253.00 | 34.93 | 27437.00 | 4022.68 | 2025-3-24T15:19:10Z
24.65 | 102254.00 | 34.67 | 30305.00 | 4022.68 | 2025-3-24T15:19:43Z

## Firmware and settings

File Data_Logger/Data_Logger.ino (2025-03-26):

#include <Arduino.h>
#include <stdint.h>
#include "sdcard.h"
#include "bme680_sensor.h"
#include "eeprom.h"
#include "rtc.h"
#include "liquidsensor.h"

// Edit Here
#define AMOUNTOFVALUES 5

// There are two needed changes to reuse this sketch for your purpose
// 1) Calculate the total amount of values that needs to be collected
//    change the variable mountOfValues accordingly
// 2) Write a Getter Function for reading the new added Sensor Type
//    and use it here (Important the Return Value has to be long)

// Environment Data Storage
long environmentValues[AMOUNTOFVALUES];
unsigned long timestamp;  // Declaration for using it in the loop

// Checking Module Avalablity
bool sd_ok = false;
bool eeprom_ok = false;
bool bme_ok = false;
bool rtc_ok = false;
bool liquidsensor_ok = false;



// Function for Getting all the Data from all the Sensors
void get_Values() {

  // Get the Values of the Environment Sensor
  get_Environment(environmentValues);
  environmentValues[4] = (long) getCurrent();

  // Append here other Sensors ....
}

void setup() {

  if (esp_sleep_get_wakeup_cause() == ESP_SLEEP_WAKEUP_TIMER) {
    Serial.println("woke up from deep sleep!");
  } else {
    Serial.println("normal start!");
  }

  Serial.begin(115200);
 
  delay(100);  // wait until serial communication established

  Serial.println("ESP32 startet...");

  //  initialise sd card module
  for (int i = 0; i < 3; i++) {  // try 3 times
    if (sdcard_init()) {
      sd_ok = true;
      break;
    }
    Serial.println("⚠️ sd-card-init failed, please retry...");
    delay(500);
  }

  // initialise eeprom
  for (int i = 0; i < 3; i++) {
    if (eeprom_init()) {
      eeprom_ok = true;
      break;
    }
    Serial.println("⚠️ EEPROM-Init failed, please retry...");
    delay(500);
  }

  // initialise bme680 module
  for (int i = 0; i < 3; i++) {
    if (bme680_init()) {
      bme_ok = true;
      break;
    }
    Serial.println("⚠️ BME680-Init failed, please retry...");
    delay(500);
  }

  // initialise rtc module
  for (int i = 0; i < 3; i++) {
    if (rtc_init()) {
      rtc_ok = true;
      break;
    }
    Serial.println("⚠️ RTC-Init failed, please retry...");
    delay(500);
  }
  
  
  // initialise liquidsensor
  for (int i = 0; i < 3; i++) {
    if (liquidsensor_init()) {
      liquidsensor_ok = true;
      break;
    }
    Serial.println("⚠️ Liquidsensor-Init failed, please retry...");
    delay(500);
  }

  

  if (!sd_ok || !eeprom_ok || !bme_ok || !rtc_ok || !liquidsensor_ok ) {
    Serial.println("🚨 Failed to initialising one ore more modules ! restarting...");
    delay(5000);
    ESP.restart();
  }

  Serial.println("✅ Successfully initialised all modules !");
}

void loop() {

  // get current timestamp
  timestamp = rtcGetTimeLong();
  Serial.print("Timestamp: ");
  Serial.println(timestamp);
  // get current values of the sensor
  get_Values();

  // combine timestamp and current values

  long data[AMOUNTOFVALUES + 1];
  memcpy(data, environmentValues, AMOUNTOFVALUES * sizeof(long));
  memcpy(data + AMOUNTOFVALUES, &timestamp, sizeof(long));


  // get the length of the sensor value array
  size_t size = AMOUNTOFVALUES + 1;

  // write the data to the EEPROM
  writeData(data, size);

  String log_entry = combineToString(data, size);

  // Write the log into the sd card
  writeFile("/data.csv", log_entry.c_str());


  Serial.println("Sleeping for 30 seconds !");
  // Deep Sleep
  esp_sleep_enable_timer_wakeup(30 * 1000000);  // 5 Min = 5 * 60 = 300 seconds * 1 000 000 mikroseconds = 300 000 000 microseconds
  esp_deep_sleep_start();
}

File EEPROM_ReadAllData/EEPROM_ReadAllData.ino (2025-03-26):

#include <Arduino.h> // included for Type String
#include <stdint.h>  // included for Type uint16/8_t
#include "rtc.h"
#include "sdcard.h"
#include "eeprom.h"
#include "calculator.h"


// Value Size

int valueSize = 6;

void setup() {

  // Initialising Serial
  Serial.begin(115200);
  while (!Serial && millis() < 5000) { delay(100); }

  // Instantiate SD-Card and EEPROM
  eeprom_init();
  sdcard_init();

  // Get Meta Data
  String meta = getMetaData();
  
  // Write Meta Data to Sd Card
  writeFile("/Eeprom.csv", meta.c_str());
  Serial.print("Write Success");

  // Varaibales for getting Sensor Data
  String buffer = "";
  uint16_t readAmount = 120; // amount of how many values has to be read (if all possible values (262.144 - 8(Meta) = 262.136 / 4 (Bytes per Value) = 65.534))
  uint16_t counterAddress = 8;

  // Loop for Concate Sensor Values
  for (int i = 0; i < readAmount; i++) {

    // if it is not the first iteration and 32 Bytes (8 Values) are already in the Buffer (set the size of values to 32Bytes to avoid Stack Overflow)
    if ( counterAddress > 0 && (counterAddress - 8) % 32 == 0) {

      buffer = buffer + getSensorData(counterAddress,i,valueSize);
      // Write to Sd Card
      writeFile("/Eeprom.csv", buffer.c_str());

      // empty the buffer string
      buffer = "";
    }
    // if it is the first iteration and no 32  Bytes are in the Buffer
    else {
      buffer = buffer + getSensorData(counterAddress,i,valueSize);
    }
   

    // increase the counter by 4 (4Bytes for 1 value)
    counterAddress = counterAddress + 4;

  }

  // Serial Print Success
  Serial.println("Writing Successful!");
  }

void loop() {
}

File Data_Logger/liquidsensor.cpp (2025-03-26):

#include "liquidsensor.h"
#include <Arduino.h>


bool liquidsensor_init(){
   // Setup
	pinMode(WB_IO1, OUTPUT | PULLUP);
	digitalWrite(WB_IO1, HIGH);

	adcAttachPin(WB_A1);

	analogSetAttenuation(ADC_11db);
	analogReadResolution(12);
  return true;
}


unsigned long getCurrent(){
  int i;
	int sensor_pin = WB_A1; // select the input pin for the potentiometer
	int mcu_ain_raw = 0;
	int average_adc_raw;
	float voltage_mcu_ain;  //mv as unit
	float current_sensor; // variable to store the value coming from the sensor

	for (i = 0; i < NO_OF_SAMPLES; i++)
	{
		mcu_ain_raw += analogRead(sensor_pin);
	}
	average_adc_raw = mcu_ain_raw / NO_OF_SAMPLES;

	voltage_mcu_ain = esp_adc_cal_raw_to_voltage(average_adc_raw);

	current_sensor = voltage_mcu_ain / 149.9*1000; //WisBlock RAK5801 (0 ~ 20mA) I=U/149.9 (mA)
	
  unsigned long curr = (unsigned long)(current_sensor *100);

  return curr;
}

//20 Point lookup tables, covering ADC readings from 2880 to 4096, step size of 64
const uint32_t lut_adc1_low[LUT_POINTS] = {2240, 2297, 2352, 2405, 2457, 2512, 2564, 2616, 2664, 2709,
                                                  2754, 2795, 2832, 2868, 2903, 2937, 2969, 3000, 3030, 3060};
const uint32_t lut_adc1_high[LUT_POINTS] = {2667, 2706, 2745, 2780, 2813, 2844, 2873, 2901, 2928, 2956,
                                                   2982, 3006, 3032, 3059, 3084, 3110, 3135, 3160, 3184, 3209};
//Only call when ADC reading is above threshold
uint32_t calculate_voltage_lut(uint32_t adc, uint32_t vref)
{
    //Get index of lower bound points of LUT
    uint32_t i = (adc - LUT_LOW_THRESH) / LUT_ADC_STEP_SIZE;

    //Let the X Axis be Vref, Y axis be ADC reading, and Z be voltage
    int x2dist = LUT_VREF_HIGH - vref;                 //(x2 - x)
    int x1dist = vref - LUT_VREF_LOW;                  //(x - x1)
    int y2dist = ((i + 1) * LUT_ADC_STEP_SIZE) + LUT_LOW_THRESH - adc;  //(y2 - y)
    int y1dist = adc - ((i * LUT_ADC_STEP_SIZE) + LUT_LOW_THRESH);        //(y - y1)

    //For points for bilinear interpolation
    int q11 = lut_adc1_low[i];                    //Lower bound point of low_vref_curve
    int q12 = lut_adc1_low[i + 1];                //Upper bound point of low_vref_curve
    int q21 = lut_adc1_high[i];                   //Lower bound point of high_vref_curve
    int q22 = lut_adc1_high[i + 1];               //Upper bound point of high_vref_curve

    //Bilinear interpolation
    //Where z = 1/((x2-x1)*(y2-y1)) * ( (q11*x2dist*y2dist) + (q21*x1dist*y2dist) + (q12*x2dist*y1dist) + (q22*x1dist*y1dist) )
    int voltage = (q11 * x2dist * y2dist) + (q21 * x1dist * y2dist) + (q12 * x2dist * y1dist) + (q22 * x1dist * y1dist);
    voltage += ((LUT_VREF_HIGH - LUT_VREF_LOW) * LUT_ADC_STEP_SIZE) / 2; //Integer division rounding
    voltage /= ((LUT_VREF_HIGH - LUT_VREF_LOW) * LUT_ADC_STEP_SIZE);    //Divide by ((x2-x1)*(y2-y1))
    return (uint32_t)voltage;
}

inline int decode_bits(uint32_t bits, uint32_t mask, bool is_twos_compl)
{
    int ret;
    if (bits & (~(mask >> 1) & mask)) 
    {      
        //Check sign bit (MSB of mask)
        //Negative
        if (is_twos_compl) 
        {
            ret = -(((~bits) + 1) & (mask >> 1));   //2's complement
        } 
        else 
        {
            ret = -(bits & (mask >> 1));    //Sign-magnitude
        }
    } 
    else 
    {
        //Positive
        ret = bits & (mask >> 1);
    }
    return ret;
}


uint32_t read_efuse_vref(void) {
    esp_adc_cal_characteristics_t adc_chars;
    
    // Charakterisiere den ADC mit Standard-VREF 1100 mV
    esp_adc_cal_characterize(ADC_UNIT_1, ADC_ATTEN_DB_11, ADC_WIDTH_BIT_12, 1100, &adc_chars);
    
    // Gib die ausgelesene eFuse-VREF zurück
    return adc_chars.vref;
}


inline uint32_t interpolate_two_points(uint32_t y1, uint32_t y2, uint32_t x_step, uint32_t x)
{
    //Interpolate between two points (x1,y1) (x2,y2) between 'lower' and 'upper' separated by 'step'
    return ((y1 * x_step) + (y2 * x) - (y1 * x) + (x_step / 2)) / x_step;
}

uint32_t esp_adc_cal_raw_to_voltage(uint32_t adc_raw)
{
	uint32_t vref = read_efuse_vref();

	uint32_t lut_voltage = calculate_voltage_lut(adc_raw, vref);
	if (adc_raw >= LUT_LOW_THRESH) 
    {
		if(adc_raw <= LUT_HIGH_THRESH)
        {
			uint32_t linear_voltage = (((((vref * 196602 / 4096)) * adc_raw) + (65536/2)) / 65536) + 142;
			return interpolate_two_points(linear_voltage, lut_voltage, LUT_ADC_STEP_SIZE, (adc_raw - LUT_LOW_THRESH));
		} 
        else 
        {
			return lut_voltage;
		}
	}
    else if (adc_raw == 0) 
    {
        return 0;
    }
	else 
    {
		return ((((((vref * 196602 /4096 ) * adc_raw) + (65536/2))) / 65536) + 142);
	}
}

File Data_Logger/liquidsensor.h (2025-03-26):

#ifndef LIQUIDSENSOR_H
#define LIQUIDSENSOR_H

#include <Arduino.h>
#include <stdint.h>
#include "esp_adc_cal.h"  

// Lookup-Tabelle und ADC-Kalibrierung
#define LUT_POINTS                     20
#define LUT_VREF_LOW                   1000
#define LUT_VREF_HIGH                  1200
#define LUT_ADC_STEP_SIZE              64
#define LUT_LOW_THRESH                 2880
#define LUT_HIGH_THRESH                (LUT_LOW_THRESH + LUT_ADC_STEP_SIZE)

#define VREF_OFFSET                    1100
#define VREF_STEP_SIZE                 7
#define VREF_MASK                      0x1F

#define NO_OF_SAMPLES                  128  

// Funktionsdeklarationen
bool liquidsensor_init();
unsigned long getCurrent();
uint32_t calculate_voltage_lut(uint32_t adc, uint32_t vref);
uint32_t read_efuse_vref(void);
uint32_t esp_adc_cal_raw_to_voltage(uint32_t adc_raw);
int decode_bits(uint32_t bits, uint32_t mask, bool is_twos_compl);
uint32_t interpolate_two_points(uint32_t y1, uint32_t y2, uint32_t x_step, uint32_t x);

#endif  // LIQUIDSENSOR_H

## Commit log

2025-03-14 solved setCounter function Problem
    [eeprom.cpp]
2025-03-17 correction of eeprom functions and refactor of the main function
    [Data_Logger.ino, eeprom.cpp]
2025-03-17 completed code of Writing to Sd-Card and EEPROM
    [data.csv]
2025-03-18 erased the content of folder Assets , Added the folder Tests with Test Results , corrected the mistakes in the function writeData from file eeprom.cpp
    [data.csv]
2025-03-18 corrected the Start Byte in Erase.cpp changed the address from 0x24 to 0x20 9.th byte instead of 10.th byte
    [Eraser.ino]
2025-03-19 corrected problem with little and big endian and the problem with configuration sketch where the meta data was set incorrect during erase it should has 0x00 but it had 0xff
    [Data_Logger.ino, eeprom.cpp, sdcard.cpp]
2025-03-20 review of the decoder for writing into sd , fixed problems 1) 0xff values of the configuration during erase 2) divide by 100 by timestamp
    [EEPROM_ReadAllData.ino, eeprom.cpp, sdcard.cpp]
2025-03-20 startedd with rtc encoder and decoder
2025-03-21 replaced delay with deepsleep function
    [Data_Logger.ino]
2025-03-21 utc problem solved , integrated successfully
    [EEPROM_ReadAllData.ino, rtc.cpp]
2025-03-24 fixed problem with inti of rtc , to be done : timeformat
    [Data_Logger.ino, Eraser.ino, eeprom.cpp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]
2025-03-24 fixed errors of timestaamp in the erase.ino and data logger.ino
    [Eraser.ino, rtc.cpp]
2025-03-24 fixed all bugs and checked the functionalitys , also tested every module if its working properly
    [Data_Logger.ino, rtc.cpp]
2025-03-24 added to test folder the current results of reading the content of sd and eeprom
    [Eeprom.csv, data.csv]
2025-03-26 fixed bugs (timestamp , csv etc.)
    [Eeprom.csv, data.csv]
2025-03-26 replaced old assets with current version
2025-03-26 Rename power_efficiency _with_sensor.png to power_efficiency_with_sensor.png
2025-03-27 Added Case Design Assets
2025-03-27 added 3d model files .stl and .f3d
    [box4u.f3d, box4u.stl]
